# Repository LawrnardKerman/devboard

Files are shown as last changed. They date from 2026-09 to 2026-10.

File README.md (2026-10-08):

### devboard
this is a silly devboard with a rp2040 and battery controller, it should work with most single cell lipo batteries


there's 16MB of flash memory by default, you can just change it in the bom, the prod files are for jlcpcb pcb assembly
it *should* work as a raspberry pi pico because most of the components are the same
there's a 3.3v in and gnd connector next to the battery connector
you can just use it like any other microcontroller
basically, this is just a fun, simple microcontroller

devboard-1
I've been really addicted to pcb design so this project is just a practice for pcb design
hope you like it :3 

ps: like 4 weeks later i dont care about pcb design anymore
and the actually production bom doesnt have the price values just so it doesn't mess with jlcpcb's bom system

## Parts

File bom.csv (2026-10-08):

Designator | Footprint | Quantity | Value | LCSC Part # | per unit price($) | total price($) | note
C1, C10, C2, C7 | 1005 | 4 | 100n | C1525 | $0.0045 | $0.02
C11, C12 | 1005 | 2 | 15p | C1548 | $0.0038 | $0.01
C13, C14, C9 | 1005 | 3 | 10u | C15525 | $0.0256 | $0.08
C3, C4, C5, C8 | 1005 | 5 | 2u2 | C12530 | $0.0053 | $0.03
C6 | 1005 | 1 | 1n | C1523 | $0.0042 | $0.01
D1, D4 | 201 | 2 | green | C2290 | $0.0122 | $0.02
D2 | 201 | 1 | RED | C2286 | $0.0122 | $0.01
D3 | D_SOD-123F | 1 | MBR1020VL | C49231015 | $0.0955 | $0.10
D5 | 1005 | 1 | D | C94366 | $0.1147 | $8.72 | note: min amount on jlc pcb is 78 | extended
Q1 | SOT-523 | 1 | DMG1012T | C2830301 | $0.0371 | $0.04
R1, R2 | 1005 | 2 | 27 | C174257 | $0.0007 | $0.01
R10, R11, R5 | 1005 | 3 | 100k | C25741 | $0.0024 | $0.01
R12 | 1005 | 1 | 5k6 | C174239 | $0.0017 | $0.01
R13 | 1005 | 1 | 10k | C25744 | $0.0034 | $0.01
R14, R15 | 1005 | 2 | 5.1 | C25128 | $0.0034 | $8.77 | note: min amount on jlc is 2578 | extended
R16 | 1005 | 1 | 2.2k | C25879 | $0.0013 | $0.01
R3 | 1005 | 1 | 1 | C22369188 | $0.0011 | $0.01
R4 | 1005 | 1 | 200 | C25087 | $0.0029 | $0.01
R6 | 1005 | 1 | 200k | C25764 | $0.0018 | $0.01
R7, R8,R17, R18 | 1005 | 2 | 1k | C11702 | $0.0018 | $0.01
R9 | 1005 | 1 | 470r | C25117 | $0.0027 | $0.01
SW1 | SW_Push_1P1T_NO_CK_KMR2 | 1 | SW_Push | C72443 | $0.6503 | $0.65 |  | extended
U1 | QFN-56-1EP_7x7mm_P0.4mm_EP3.2x3.2mm | 1 | RP2040 | C2040 | $0.9884 | $0.99 |  | extended
U2 | WSON-8-1EP_8x6mm_P1.27mm_EP3.4x4.3mm | 1 | W25Q128JVE | C2456297 | $4.0886 | $4.09 | 16MB | extended
U3 | WSON-10-1EP_2.5x2.5mm_P0.5mm_EP1.2x2mm_ThermalVias | 1 | TPS63031DSK | C15516 | $1.0291 | $1.03 |  | extended
U4 | SOT-23-5 | 1 | MCP73831-2-OT | C14879 | $1.3006 | $1.30 |  | extended
Y1 | Crystal_SMD_5032-2Pin_5.0x3.2mm | 1 | 12MHz | C295065 | $0.3489 | $0.35 |  | extended
J1 | USB_C_Receptacle_G-Switch_GT-USB-7010ASV | 1 | USB_C_Receptacle_USB2.0_16P | C2927037 | $0.1441 | $0.14 |  | extended
L1 | 1005 | 1 | 2u2 | C84472 | $0.0174 | $0.02 |  | extended
total component cost |  |  |  |  |  | $26.48
pcb cost |  |  |  |  |  | $5.10 | 5 pcbs
pcba cost |  |  |  |  |  | $80.36 | includes components(2 boards)
subtotal |  |  |  |  |  | $85.46 | not counting taxes & shipping
shipping |  |  |  |  |  | $3.12 | global standard direct
total |  |  |  |  |  | $88.58 | not including taxes

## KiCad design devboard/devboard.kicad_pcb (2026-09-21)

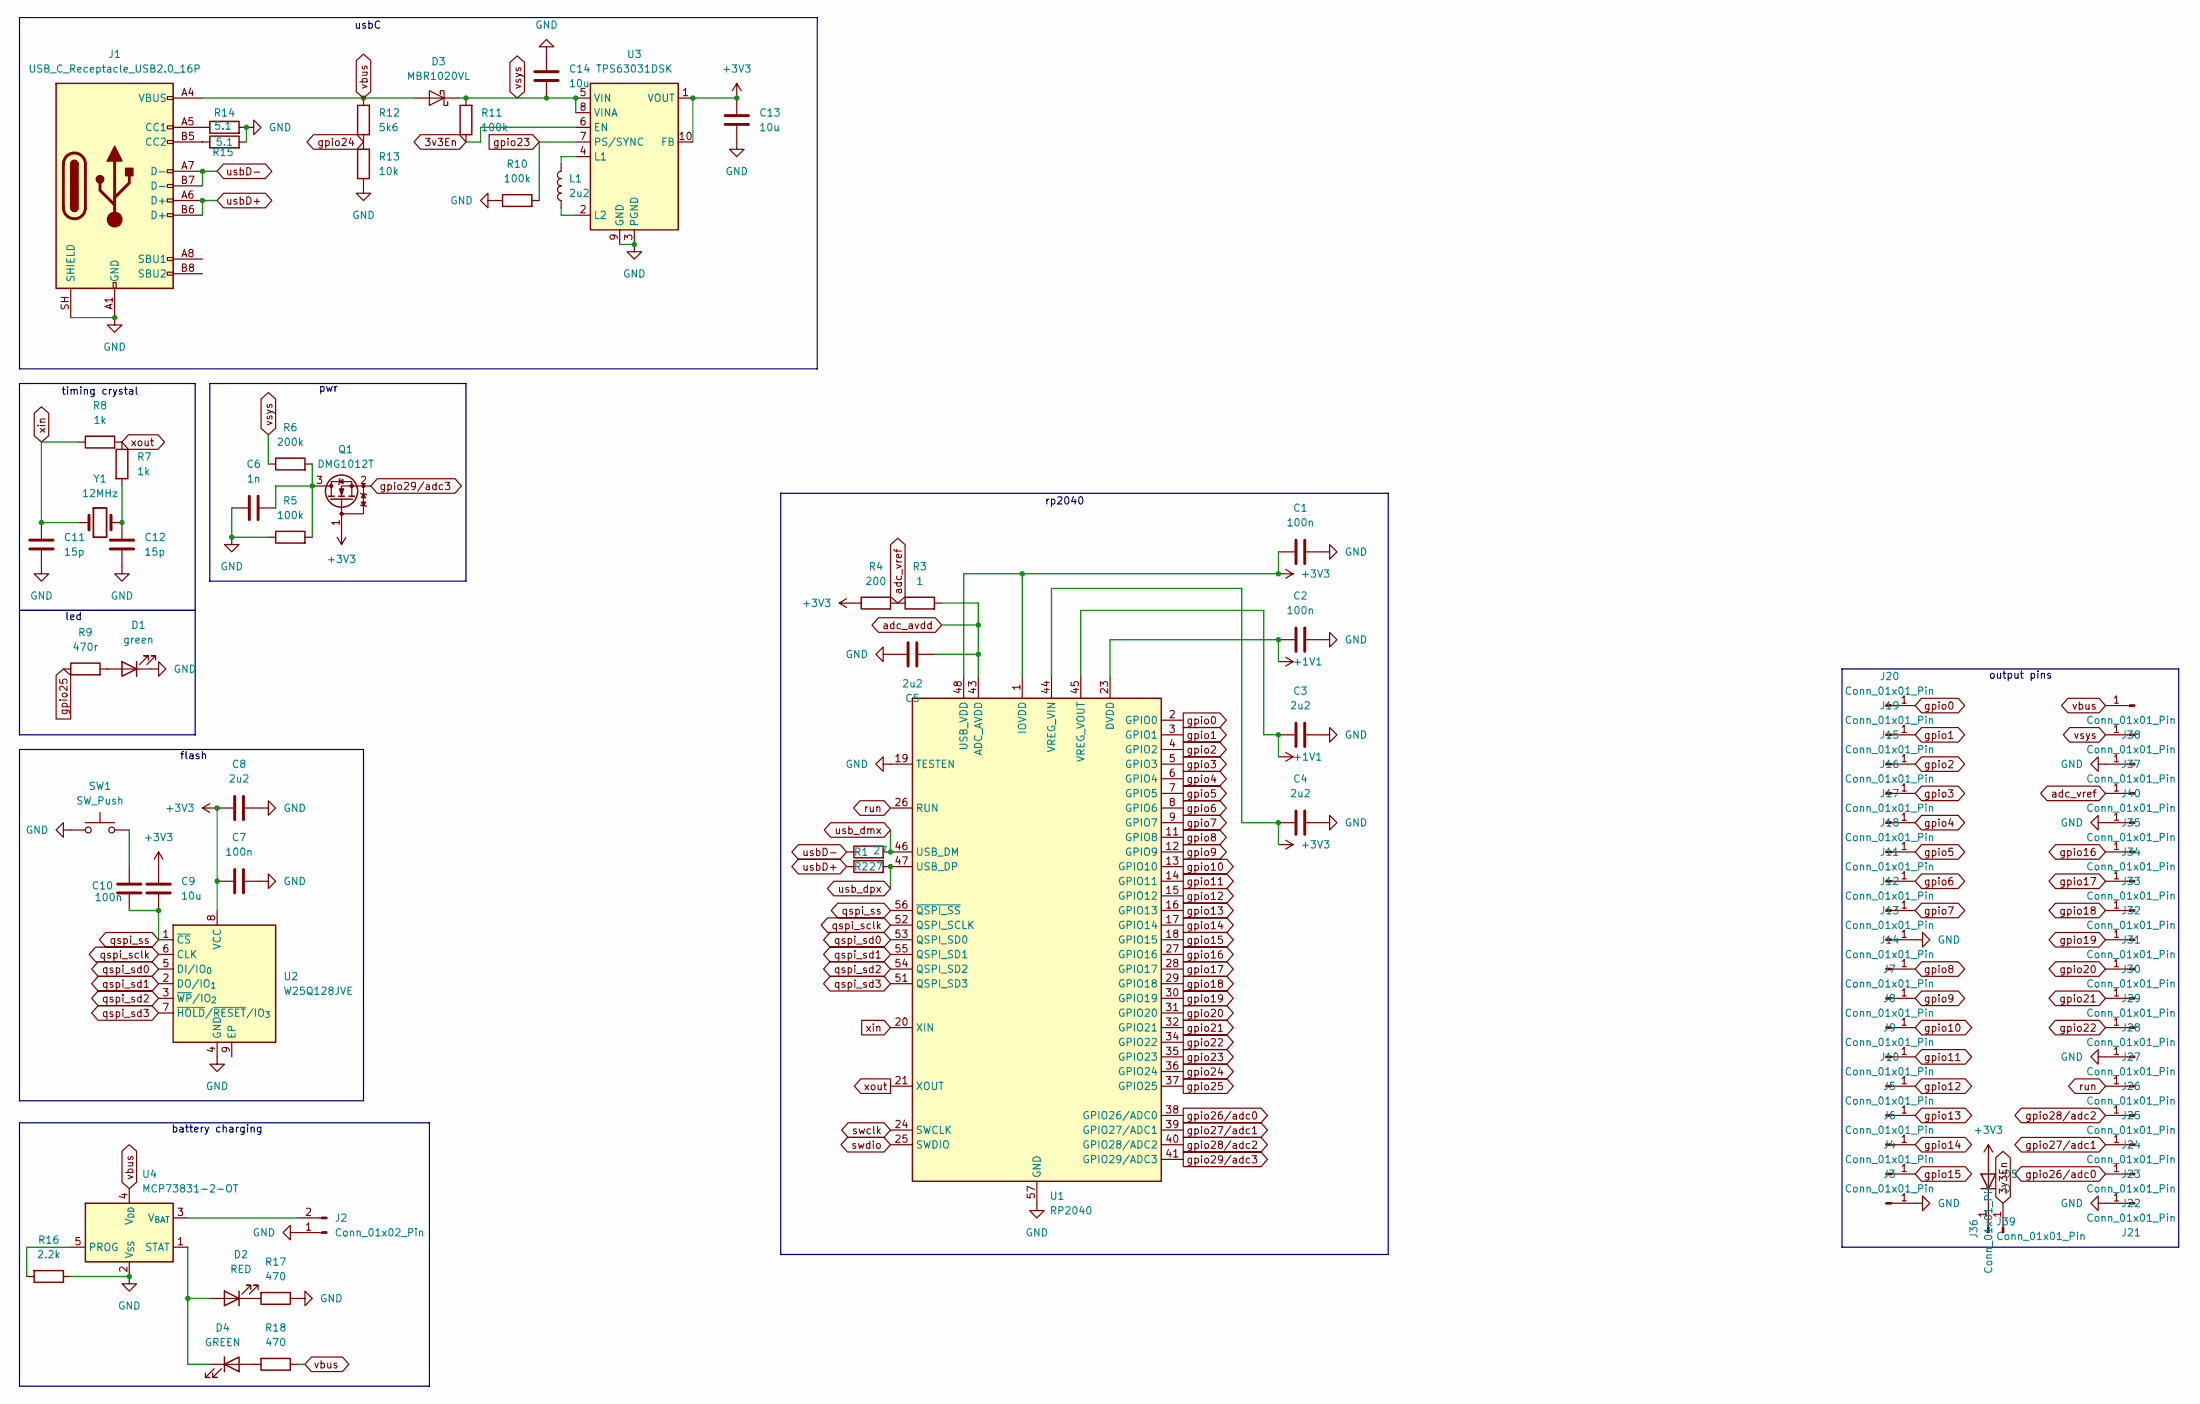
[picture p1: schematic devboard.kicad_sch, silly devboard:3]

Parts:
C1, C2, C7, C10: 100n; C_01005_0402Metric
C3, C4, C5, C8: 2u2; C_01005_0402Metric
C6: 1n; C_01005_0402Metric
C9, C13, C14: 10u; C_01005_0402Metric
C11, C12: 15p; C_01005_0402Metric
D1: green; LED_0201_0603Metric
D2: RED; LED_0201_0603Metric
D3: MBR1020VL; D_SOD-123F
D4: GREEN; LED_0201_0603Metric
D5: D; D_01005_0402Metric
J1: USB_C_Receptacle_USB2.0_16P; USB_C_Receptacle_G-Switch_GT-USB-7010ASV
J2: Conn_01x02_Pin; JST_PH_S2B-PH-K_1x02_P2.00mm_Horizontal
J3, J4, J5, J6, J7, J8, J9, J10, J11, J12, J13, J14, J15, J16, J17, J18, J19, J20, J21, J22, J23, J24, J25, J26, J27, J28, J29, J30, J31, J32, J33, J34, J35, J36, J37, J38, J39, J40: Conn_01x01_Pin; edgeConnectorPad
L1: 2u2; L_01005_0402Metric
Q1: DMG1012T; SOT-523
R1, R2: 27; R_01005_0402Metric
R3: 1; R_01005_0402Metric
R4: 200; R_01005_0402Metric
R5, R10, R11: 100k; R_01005_0402Metric
R6: 200k; R_01005_0402Metric
R7, R8: 1k; R_01005_0402Metric
R9: 470r; R_01005_0402Metric
R12: 5k6; R_01005_0402Metric
R13: 10k; R_01005_0402Metric
R14, R15: 5.1; R_01005_0402Metric
R16: 2.2k; R_01005_0402Metric
R17, R18: 470; R_01005_0402Metric
SW1: SW_Push; SW_Push_1P1T_NO_CK_KMR2
U1: RP2040; QFN-56-1EP_7x7mm_P0.4mm_EP3.2x3.2mm
U2: W25Q128JVE; WSON-8-1EP_8x6mm_P1.27mm_EP3.4x4.3mm
U3: TPS63031DSK; WSON-10-1EP_2.5x2.5mm_P0.5mm_EP1.2x2mm_ThermalVias
U4: MCP73831-2-OT; SOT-23-5
Y1: 12MHz; Crystal_SMD_5032-2Pin_5.0x3.2mm

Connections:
3v3En: J36.1 (Pin_1_1), R11.1, U3.6 (EN)
+1V1: C2.1, C3.1, U1.23 (DVDD), U1.45 (VREG_VOUT), U1.50 (DVDD)
+3V3: C1.1, C4.1, C7.1, C8.1, C9.2, C13.1, D5.2 (A), Q1.1 (G), R4.1, U1.1 (IOVDD), U1.10 (IOVDD), U1.22 (IOVDD), U1.33 (IOVDD), U1.42 (IOVDD), U1.44 (VREG_VIN), U1.48 (USB_VDD), U1.49 (IOVDD), U2.8 (VCC), U3.1 (VOUT), U3.10 (FB)
GND: C1.2, C2.2, C3.2, C4.2, C5.2, C6.1, C7.2, C8.2, C11.2, C12.2, C13.2, C14.1, D1.1 (K), J1.A1 (GND), J1.A12 (GND), J1.B1 (GND), J1.B12 (GND), J1.SH (SHIELD), J2.1, J3.1 (Pin_1_1), J13.1 (Pin_1_1), J21.1 (Pin_1_1), J26.1 (Pin_1_1), J34.1 (Pin_1_1), J40.1 (Pin_1_1), R5.1, R10.1, R13.1, R14.2, R15.2, R16.1, R17.1, SW1.1, U1.19 (TESTEN), U1.57 (GND), U2.4 (GND), U3.3 (PGND), U3.9 (GND), U3.11 (PGND), U4.2 (V_{SS})
unnamed: C10.2, SW1.2
unnamed: C12.1, R7.2, Y1.2
unnamed: D1.2 (A), R9.2
unnamed: D2.2 (A), D4.1 (K), U4.1 (STAT)
unnamed: D2.1 (K), R17.2
unnamed: D4.2 (A), R18.2
unnamed: D5.1 (K), J39.1 (Pin_1_1)
unnamed: J1.A5 (CC1), R14.1
unnamed: J1.B5 (CC2), R15.1
unnamed: J2.2, U4.3 (V_{BAT})
unnamed: C6.2, Q1.3 (D), R5.2, R6.2
unnamed: L1.2, U3.4 (L1)
unnamed: L1.1, U3.2 (L2)
unnamed: R16.2, U4.5 (PROG)
adc_avdd: C5.1, R3.2, U1.43 (ADC_AVDD)
adc_vref: J35.1 (Pin_1_1), R3.1, R4.2
gpio0: J20.1 (Pin_1_1), U1.2 (GPIO0)
gpio1: J19.1 (Pin_1_1), U1.3 (GPIO1)
gpio2: J15.1 (Pin_1_1), U1.4 (GPIO2)
gpio3: J16.1 (Pin_1_1), U1.5 (GPIO3)
gpio4: J17.1 (Pin_1_1), U1.6 (GPIO4)
gpio5: J18.1 (Pin_1_1), U1.7 (GPIO5)
gpio6: J11.1 (Pin_1_1), U1.8 (GPIO6)
gpio7: J12.1 (Pin_1_1), U1.9 (GPIO7)
gpio8: J14.1 (Pin_1_1), U1.11 (GPIO8)
gpio9: J7.1 (Pin_1_1), U1.12 (GPIO9)
gpio10: J8.1 (Pin_1_1), U1.13 (GPIO10)
gpio11: J9.1 (Pin_1_1), U1.14 (GPIO11)
gpio12: J10.1 (Pin_1_1), U1.15 (GPIO12)
gpio13: J5.1 (Pin_1_1), U1.16 (GPIO13)
gpio14: J6.1 (Pin_1_1), U1.17 (GPIO14)
gpio15: J4.1 (Pin_1_1), U1.18 (GPIO15)
gpio16: J33.1 (Pin_1_1), U1.27 (GPIO16)
gpio17: J32.1 (Pin_1_1), U1.28 (GPIO17)
gpio18: J31.1 (Pin_1_1), U1.29 (GPIO18)
gpio19: J30.1 (Pin_1_1), U1.30 (GPIO19)
gpio20: J29.1 (Pin_1_1), U1.31 (GPIO20)
gpio21: J28.1 (Pin_1_1), U1.32 (GPIO21)
gpio22: J27.1 (Pin_1_1), U1.34 (GPIO22)
gpio23: R10.2, U1.35 (GPIO23), U3.7 (PS/SYNC)
gpio24: R12.1, R13.2, U1.36 (GPIO24)
gpio25: R9.1, U1.37 (GPIO25)
gpio26/adc0: J22.1 (Pin_1_1), U1.38 (GPIO26/ADC0)
gpio27/adc1: J23.1 (Pin_1_1), U1.39 (GPIO27/ADC1)
gpio28/adc2: J24.1 (Pin_1_1), U1.40 (GPIO28/ADC2)
gpio29/adc3: Q1.2 (S), U1.41 (GPIO29/ADC3)
qspi_sclk: U1.52 (QSPI_SCLK), U2.6 (CLK)
qspi_sd0: U1.53 (QSPI_SD0), U2.5 (DI/IO_{0})
qspi_sd1: U1.55 (QSPI_SD1), U2.2 (DO/IO_{1})
qspi_sd2: U1.54 (QSPI_SD2), U2.3 (~WP/IO_{2})
qspi_sd3: U1.51 (QSPI_SD3), U2.7 (~HOLD/~RESET/IO_{3})
qspi_ss: C9.1, C10.1, U1.56 (~QSPI_SS), U2.1 (~CS)
run: J25.1 (Pin_1_1), U1.26 (RUN)
swclk: U1.24 (SWCLK)
swdio: U1.25 (SWDIO)
usbD+: J1.A6 (D+), J1.B6 (D+), R2.1
usbD-: J1.A7 (D-), J1.B7 (D-), R1.1
usb_dmx: R1.2, U1.46 (USB_DM)
usb_dpx: R2.2, U1.47 (USB_DP)
vbus: D3.2 (A), J1.A4 (VBUS), J1.A9 (VBUS), J1.B4 (VBUS), J1.B9 (VBUS), J38.1 (Pin_1_1), R12.2, R18.1, U4.4 (V_{DD})
vsys: C14.2, D3.1 (K), J37.1 (Pin_1_1), R6.1, R11.2, U3.5 (VIN), U3.8 (VINA)
xin: C11.1, R8.1, U1.20 (XIN), Y1.1
xout: R7.1, R8.2, U1.21 (XOUT)

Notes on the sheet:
usbC
pwr
battery charging
output pins
flash
timing crystal
led
rp2040

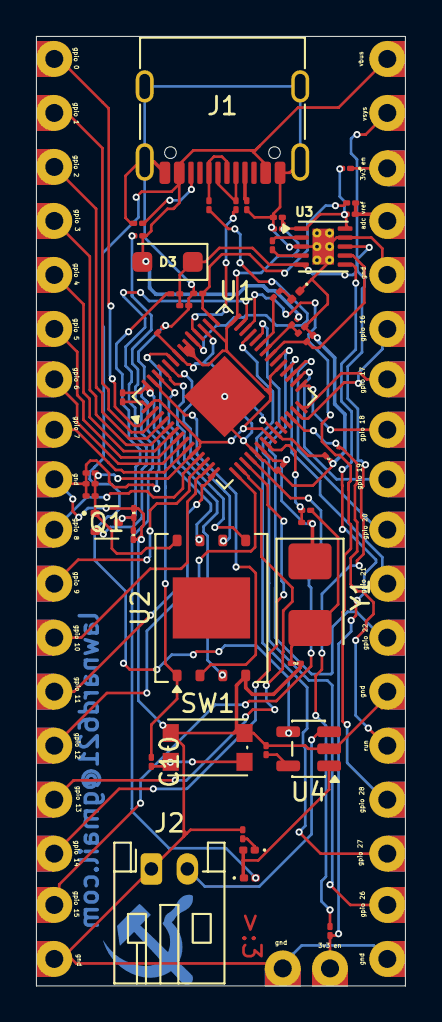
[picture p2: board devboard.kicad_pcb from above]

Board: 2 copper layers, 20.5 x 52.8 mm, 85 parts (0 on the bottom side), 65 nets.
